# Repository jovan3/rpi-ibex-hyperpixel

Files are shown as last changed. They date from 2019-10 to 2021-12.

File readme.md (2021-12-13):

# RPi Ibex (Hyperpixel edition)

RPi Ibex is a Raspberry Pi Zero based portable computer. The goal of the project is to provide a way to use Raspberry Pi Zero as a portable computer using parts that are available, cheap and relatively easy to solder (no exotic keyboard controller chips required). 

This repository contains Kicad project files for the PCB. The keyboard is just simple push buttons soldered directly on the board. The keyboard controller is an Atmega 328P.

## Board renderings

Kicad 3D renderings of the front and back of the PCB:

Front:
<p align="center">
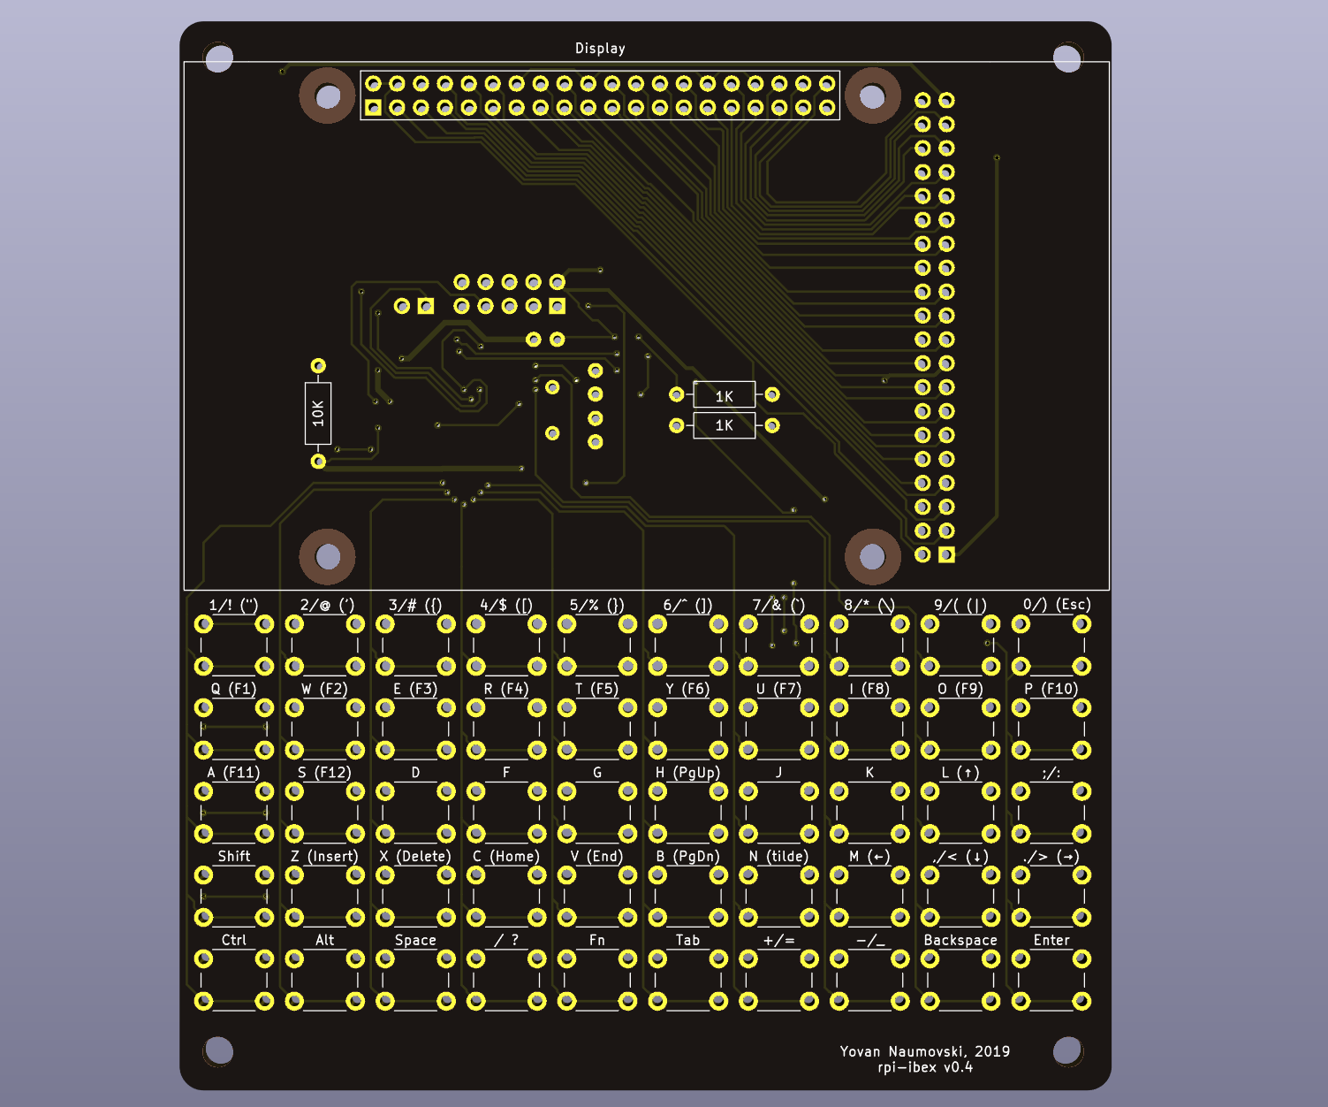
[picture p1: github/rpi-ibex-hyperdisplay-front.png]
    
</p>

Back:
<p align="center">
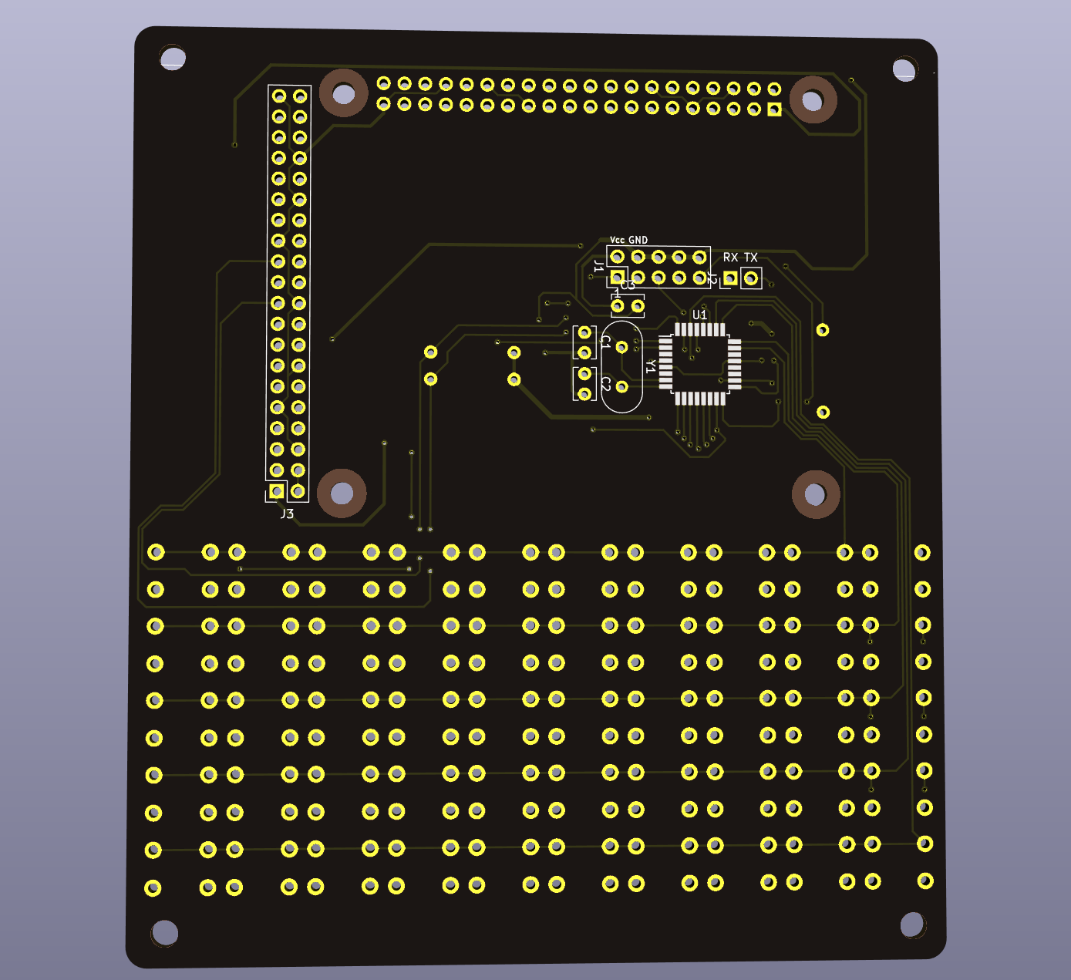
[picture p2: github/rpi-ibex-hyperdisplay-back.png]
    
</p>

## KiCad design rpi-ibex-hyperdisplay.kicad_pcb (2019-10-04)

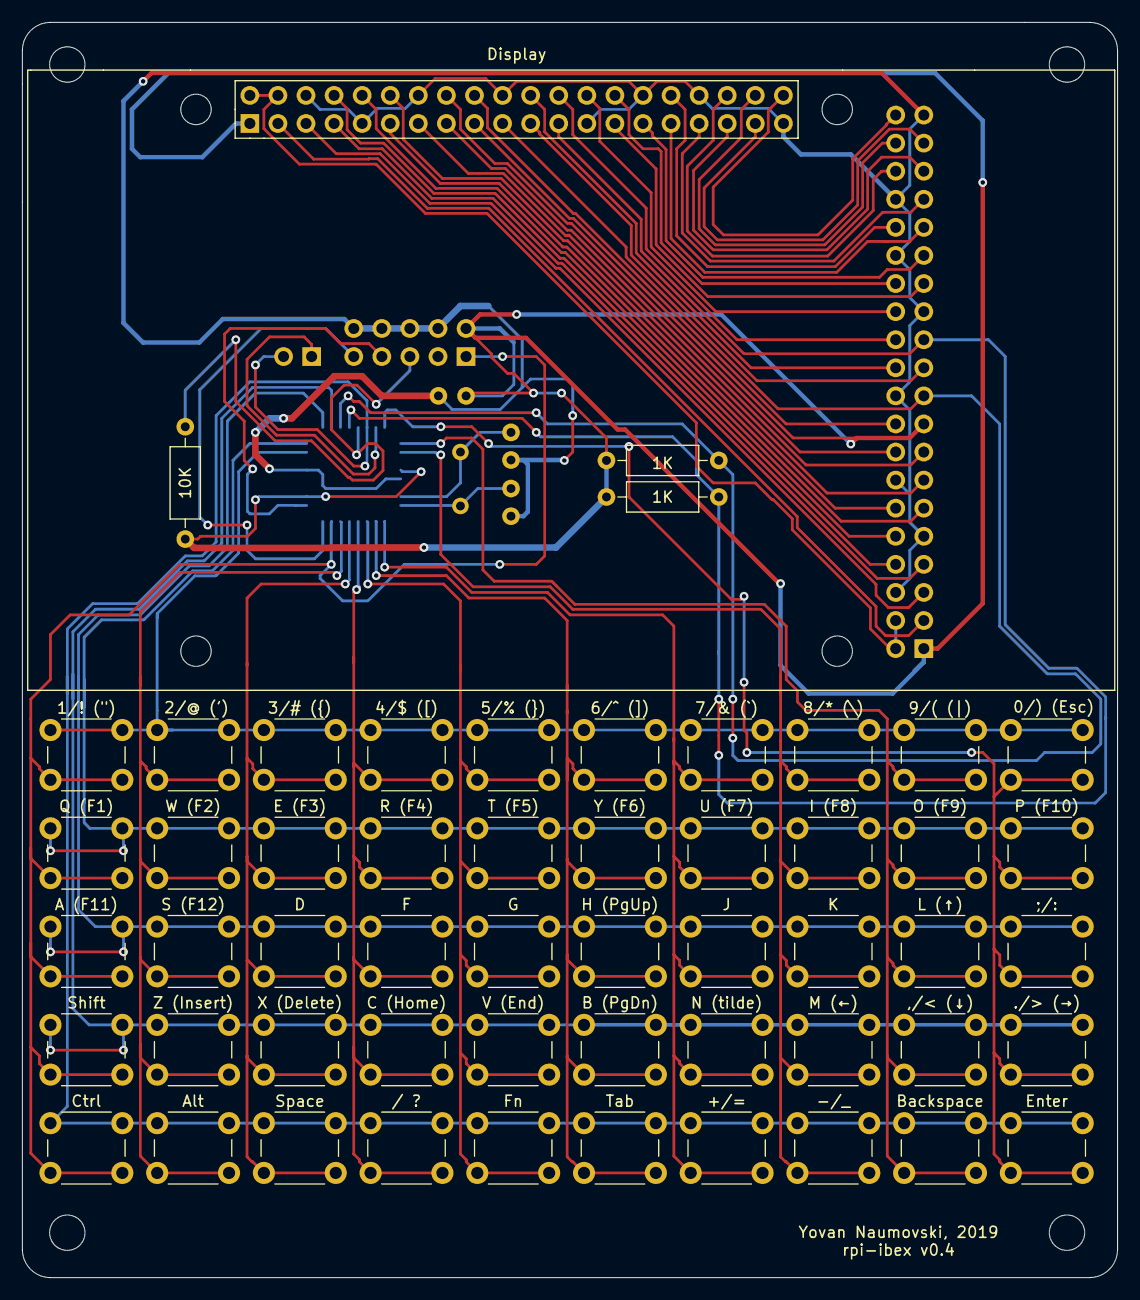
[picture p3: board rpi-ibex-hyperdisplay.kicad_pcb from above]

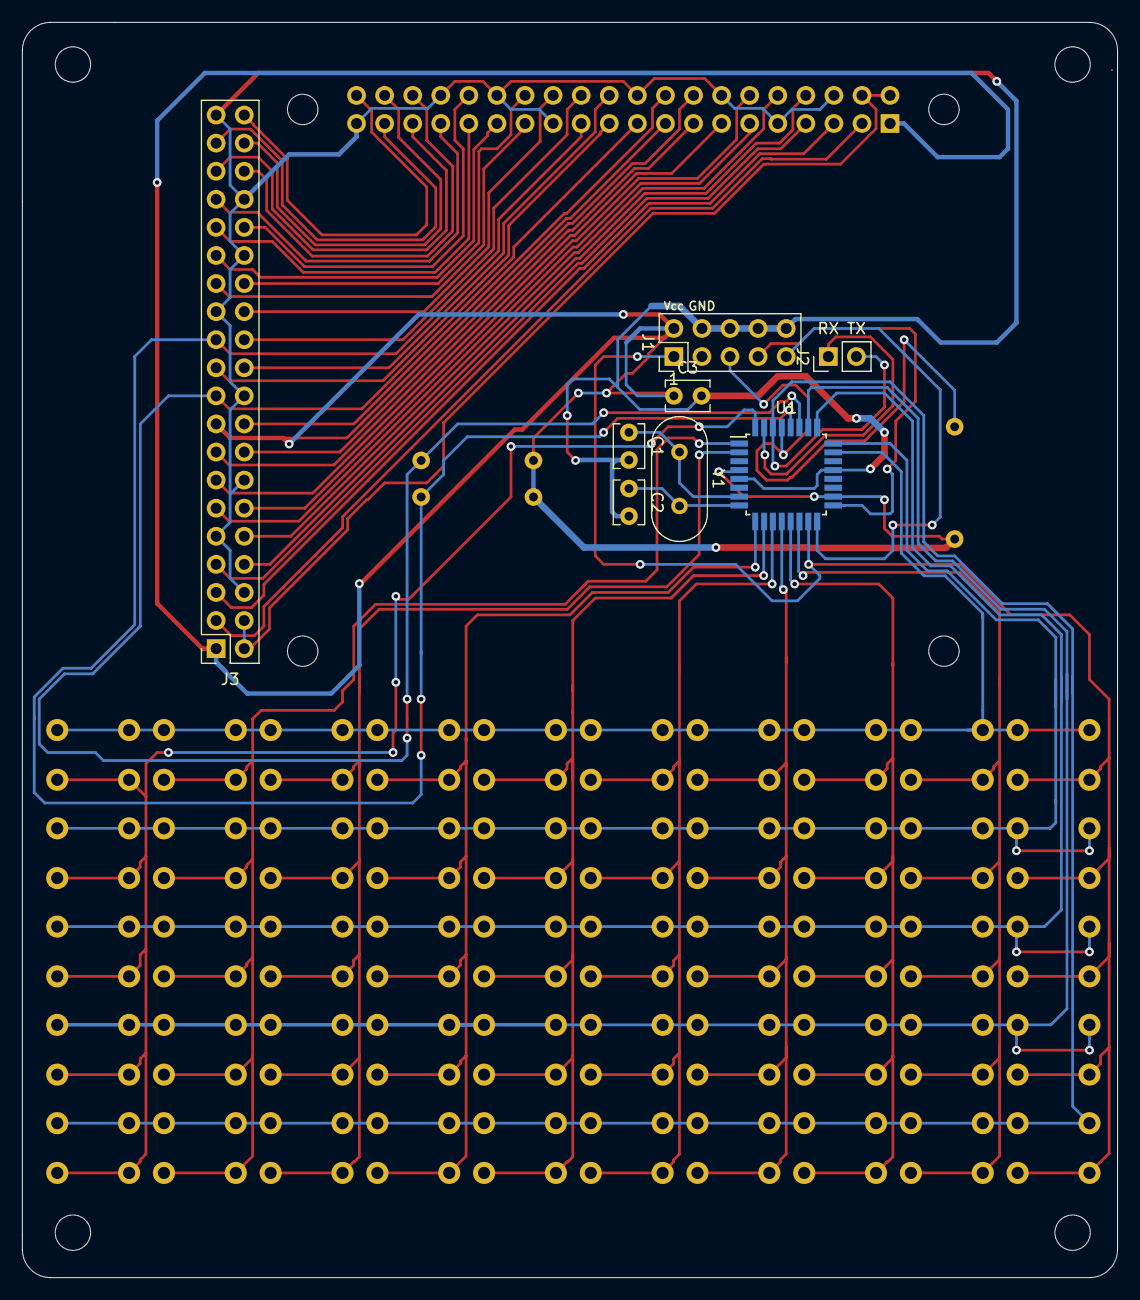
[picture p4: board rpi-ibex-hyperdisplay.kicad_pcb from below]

Board: 2 copper layers, 99.1 x 113.5 mm, 62 parts (8 on the bottom side), 52 nets.

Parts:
0/) (Esc), 1/! ("), 2/@ ('), 3/# ({), 4/$ ([), 5/% (}), 6/^ (]), 7/& (`), 8/* (\), 9/( (|), ./> (→): SW_Push; SW_PUSH_6mm_H5mm
1K, 1K#2: 1K; R_Axial_DIN0207_L6.3mm_D2.5mm_P10.16mm_Horizontal
10K: 10K; R_Axial_DIN0207_L6.3mm_D2.5mm_P10.16mm_Horizontal
+/=: SW_Push; SW_PUSH_6mm_H5mm
,/< (↓): SW_Push; SW_PUSH_6mm_H5mm
-/_: SW_Push; SW_PUSH_6mm_H5mm
/ ?: SW_Push; SW_PUSH_6mm_H5mm
;/:: SW_Push; SW_PUSH_6mm_H5mm
A (F11): SW_Push; SW_PUSH_6mm_H5mm
Alt: SW_Push; SW_PUSH_6mm_H5mm
B (PgDn): SW_Push; SW_PUSH_6mm_H5mm
Backspace: SW_Push; SW_PUSH_6mm_H5mm
C1, C2: 22pF; C_Disc_D3.8mm_W2.6mm_P2.50mm
C3: 100nF; C_Disc_D3.8mm_W2.6mm_P2.50mm
C (Home): SW_Push; SW_PUSH_6mm_H5mm
Ctrl: SW_Push; SW_PUSH_6mm_H5mm
D: SW_Push; SW_PUSH_6mm_H5mm
Display: Hyperpixel_4.0_Touch
E (F3): SW_Push; SW_PUSH_6mm_H5mm
Enter: SW_Push; SW_PUSH_6mm_H5mm
F: SW_Push; SW_PUSH_6mm_H5mm
Fn: SW_Push; SW_PUSH_6mm_H5mm
G: SW_Push; SW_PUSH_6mm_H5mm
H (PgUp): SW_Push; SW_PUSH_6mm_H5mm
I (F8): SW_Push; SW_PUSH_6mm_H5mm
J: SW_Push; SW_PUSH_6mm_H5mm
J1: Conn_02x05_Odd_Even; PinHeader_2x05_P2.54mm_Vertical
J2: USART_Connector_1; PinHeader_1x02_P2.54mm_Vertical
J3: Raspberry_Pi_2_3; PinSocket_2x20_P2.54mm_Vertical
K: SW_Push; SW_PUSH_6mm_H5mm
L (↑): SW_Push; SW_PUSH_6mm_H5mm
M (←): SW_Push; SW_PUSH_6mm_H5mm
N (tilde): SW_Push; SW_PUSH_6mm_H5mm
O (F9): SW_Push; SW_PUSH_6mm_H5mm
P (F10): SW_Push; SW_PUSH_6mm_H5mm
Q (F1): SW_Push; SW_PUSH_6mm_H5mm
R (F4): SW_Push; SW_PUSH_6mm_H5mm
S (F12): SW_Push; SW_PUSH_6mm_H5mm
Shift: SW_Push; SW_PUSH_6mm_H5mm
Space: SW_Push; SW_PUSH_6mm_H5mm
T (F5): SW_Push; SW_PUSH_6mm_H5mm
Tab: SW_Push; SW_PUSH_6mm_H5mm
U1: ATmega328PB-AU; TQFP-32_7x7mm_P0.8mm
U (F7): SW_Push; SW_PUSH_6mm_H5mm
V (End): SW_Push; SW_PUSH_6mm_H5mm
W (F2): SW_Push; SW_PUSH_6mm_H5mm
X (Delete): SW_Push; SW_PUSH_6mm_H5mm
Y1: 16MHz; Crystal_HC49-U_Vertical
Y (F6): SW_Push; SW_PUSH_6mm_H5mm
Z (Insert): SW_Push; SW_PUSH_6mm_H5mm

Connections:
5V: Display.2, Display.4, J3.2, J3.4
BCM0: Display.27, J3.27
BCM1: Display.28, J3.28
BCM2: Display.3, J3.3
BCM3: Display.5, J3.5
BCM4: Display.7, J3.7
BCM5: Display.29, J3.29
BCM6: Display.31, J3.31
BCM7: Display.26, J3.26
BCM8: Display.24, J3.24
BCM9: Display.21, J3.21
BCM10: 1K.1, Display.19, J3.19, U1.27
BCM11: 1K#2.1, Display.23, J3.23, U1.28
BCM12: Display.32, J3.32
BCM13: Display.33, J3.33
BCM14: Display.8, J3.8
BCM15: Display.10, J3.10
BCM16: Display.36, J3.36
BCM17: Display.11, J3.11
BCM18: Display.12, J3.12
BCM19: Display.35, J3.35
BCM20: Display.38, J3.38
BCM21: Display.40, J3.40
BCM22: Display.15, J3.15
BCM23: Display.16, J3.16
BCM24: Display.18, J3.18
BCM25: Display.22, J3.22
BCM26: Display.37, J3.37
BCM27: Display.13, J3.13
GND: C1.2, C2.2, C3.2, Display.6, Display.9, Display.14, Display.20, Display.25, Display.30, Display.34, Display.39, J1.4, J1.6, J1.8, J1.10, J3.6, J3.9, J3.14, J3.20, J3.25, J3.30, J3.34, J3.39, U1.5, U1.21
KB_COL_1: 1/! (").2, A (F11).2, Ctrl.2, J1.1, Q (F1).2, Shift.2, U1.15
KB_COL_2: 2/@ (').2, Alt.2, S (F12).2, U1.14, W (F2).2, Z (Insert).2
KB_COL_3: 3/# ({).2, D.2, E (F3).2, Space.2, U1.13, X (Delete).2
KB_COL_4: 4/$ ([).2, / ?.2, C (Home).2, F.2, R (F4).2, U1.12
KB_COL_5: 5/% (}).2, Fn.2, G.2, T (F5).2, U1.11, V (End).2
KB_COL_6: 6/^ (]).2, B (PgDn).2, H (PgUp).2, Tab.2, U1.10, Y (F6).2
KB_COL_7: 7/& (`).2, +/=.2, J.2, N (tilde).2, U1.9, U (F7).2
KB_COL_8: 8/* (\).2, -/_.2, I (F8).2, K.2, M (←).2, U1.2
KB_COL_9: 9/( (|).2, ,/< (↓).2, Backspace.2, L (↑).2, O (F9).2, U1.1
KB_COL_10: 0/) (Esc).2, ./> (→).2, ;/:.2, Enter.2, P (F10).2, U1.32
KB_ROW_1: 0/) (Esc).1, 1/! (").1, 2/@ (').1, 3/# ({).1, 4/$ ([).1, 5/% (}).1, 6/^ (]).1, 7/& (`).1, 8/* (\).1, 9/( (|).1, U1.23
KB_ROW_2: E (F3).1, I (F8).1, O (F9).1, P (F10).1, Q (F1).1, R (F4).1, T (F5).1, U1.24, U (F7).1, W (F2).1, Y (F6).1
KB_ROW_3: ;/:.1, A (F11).1, D.1, F.1, G.1, H (PgUp).1, J.1, K.1, L (↑).1, S (F12).1, U1.25
KB_ROW_4: ,/< (↓).1, ./> (→).1, B (PgDn).1, C (Home).1, M (←).1, N (tilde).1, Shift.1, U1.26, V (End).1, X (Delete).1, Z (Insert).1
KB_ROW_5: +/=.1, -/_.1, / ?.1, Alt.1, Backspace.1, Ctrl.1, Enter.1, Fn.1, J2.2, Space.1, Tab.1, U1.30
MISO: J1.9, U1.16
unnamed: J2.1, U1.31
RESET: 10K.1, J1.5, U1.29
RPI_3.3V: 1K.2, 1K#2.2, 10K.2, C3.1, Display.1, Display.17, J1.2, J3.1, J3.17, U1.4, U1.18
SCK: J1.7, U1.17
XTAL1: C1.1, U1.7, Y1.1
XTAL2: C2.1, U1.8, Y1.2

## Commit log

2019-09-10 change v0.2 to be designed around the Hyperpixel 4.0 touch screen
    [rpi-ibex-hyperdisplay.kicad_pcb, rpi-ibex-hyperdisplay.sch]
2019-10-02 mirror flip the hyperpixel connector (oops :/)
    [rpi-ibex-hyperdisplay.kicad_pcb, rpi-ibex-hyperdisplay.sch]
2019-10-02 move hyperpixel footprint silkscreen and other layers from back to front
    [rpi-ibex-hyperdisplay.kicad_pcb]
2019-10-03 rotate the rpi pin headers so that its usb ports are facing outwards the board
    [rpi-ibex-hyperdisplay.kicad_pcb]
2019-10-04 better route tracks layout for the connection between the raspberry pi and hyperpixel display
    [rpi-ibex-hyperdisplay.kicad_pcb]
2019-10-04 improve layout
    [rpi-ibex-hyperdisplay.kicad_pcb]
2021-12-13 add pcb images
